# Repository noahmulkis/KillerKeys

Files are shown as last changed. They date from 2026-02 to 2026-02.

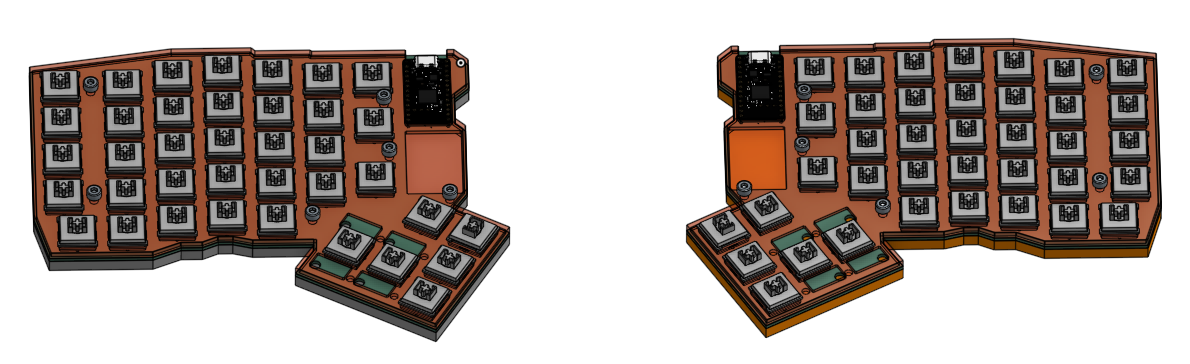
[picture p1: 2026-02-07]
Github/README/Screenshot 2026-02-07 160610.png

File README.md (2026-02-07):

# KillerKeys

This is KillerKeys, A super low profile, 3dprintable, pcb based custom keyboard, using a nice!nano knockoff mc.  

## Required Parts  
(Check BOM for exact details)

- microcontroller  
- 2x pcb (pcb is reversible)  
- 1 of each required 3d printed part  
- 6x m3x8 cap head machine screws  
- switch of choice (footprints can accomadate multiple brands, I am using reddragon low profile switches)  
- 3D printed keycaps (up to personal choice of colour / design)  
- Diodes (throughhole or smd)  

## Assembly instructions

1. Solder diodes to board top.  
2. Solder headers and microcontroller to top of board.  
3. For RHS board solder together pads to reverse direction, on LHS board solder "normal" side pads together.  
4. The microcontroller headers are needed to allow the USB-C port to be accessable.  
5. Push switches through top plates.  
6. Place top plate in place, filp board upside down, and solder the switches in place.  
7. Solder Battery onto board, and place in hole in PCB.  
8. Screw bottom case in place.  
9. Flash KMK firmware.  

## Images





Schematic

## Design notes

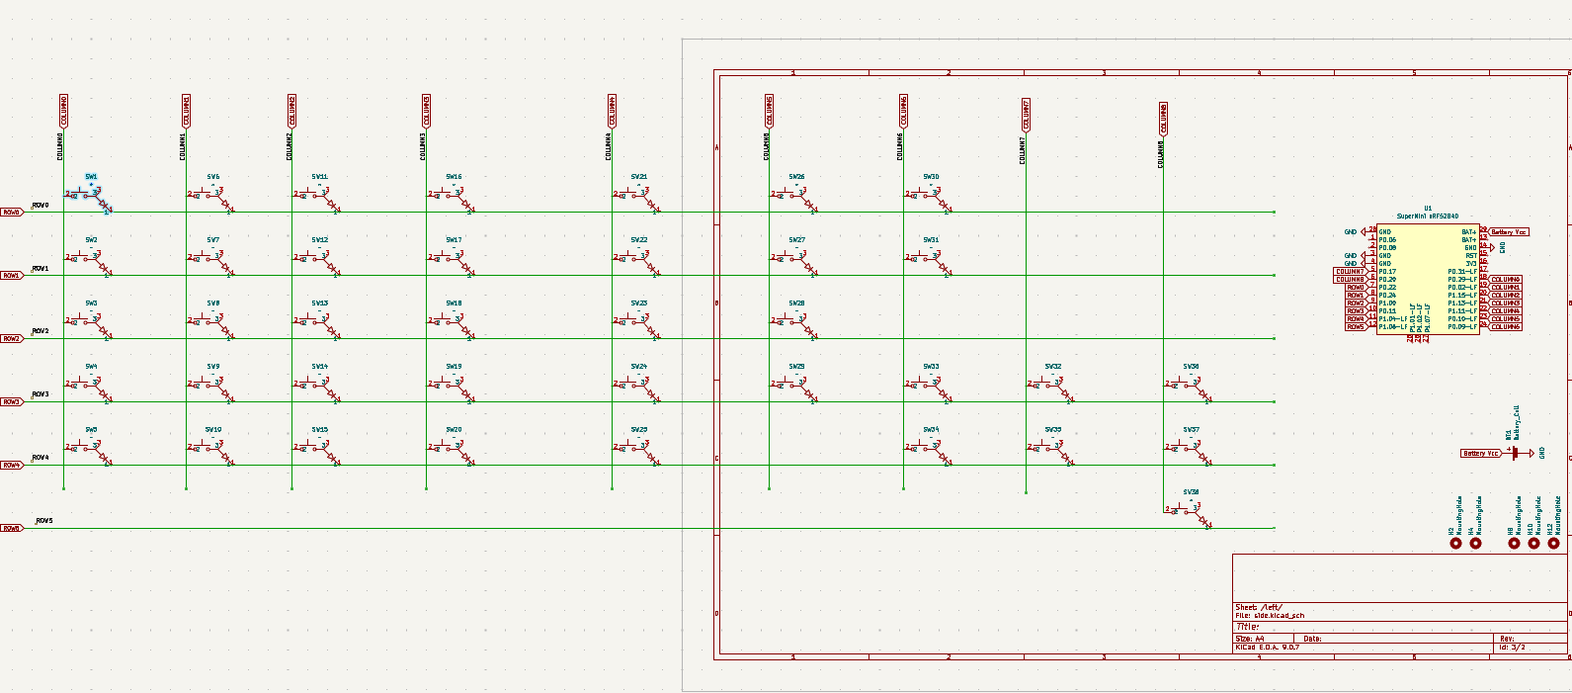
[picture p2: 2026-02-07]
Github/README/Schematic.png

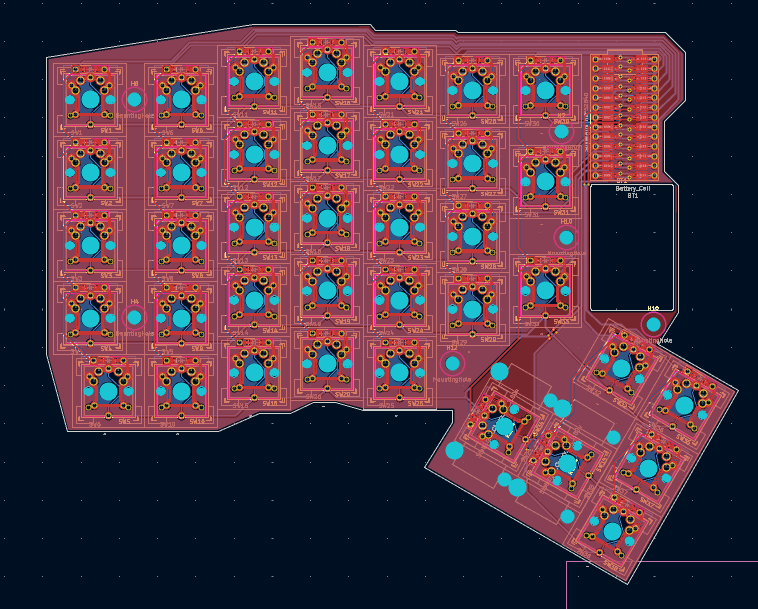
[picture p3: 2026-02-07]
Github/README/Screenshot 2026-02-07 161123.png

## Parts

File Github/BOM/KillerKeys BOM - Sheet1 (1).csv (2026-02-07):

CPN | Part Name | Description | Unit price | Quantity | Total price | Link
1 | Pro Micro nRF52840 | Microcontroller 2x | 2.83 | 2 | 5.66 | https://www.aliexpress.com/item/1005006271881076.html
2 | Switches | reddragon low profile |  |  | 10.73 | https://www.aliexpress.com/item/1005008633373890.html?curPageLogUid=tXnkem2xSMqb
3 | Diodes | 1N5819 THR DIODE 76x | 1.15 | 2 | 2.3 | https://www.aliexpress.com/item/1005001552094086.html?curPageLogUid=bXqkzmMptUZg
4 | Stabilizers | 4-2U 1- 6.25U |  |  | 10.89 | https://www.aliexpress.com/item/1005005296240590.html?curPageLogUid=bUBv3HwUEil0
5 | PCB's | JLCPCB order (both pcb's) inc. shipping | 22.4 | 1 | $14.30 | https://cart.jlcpcb.com/quote?stencilLayer=2&stencilWidth=100&stencilLength=100&stencilCounts=5&plateType=1
6 | Hardware/Screws | YMMV spprx £0 -- 6x m3x8 cap head
7 | Batteries | 1s Lipo 33x21x10mm or smaller |  | 1 | 2.06 | https://www.aliexpress.com/item/1005009176692643.html?curPageLogUid=KsSvs5md74Hk
Running Total | £45.94
Total dollars | £62.48 | plus shipping

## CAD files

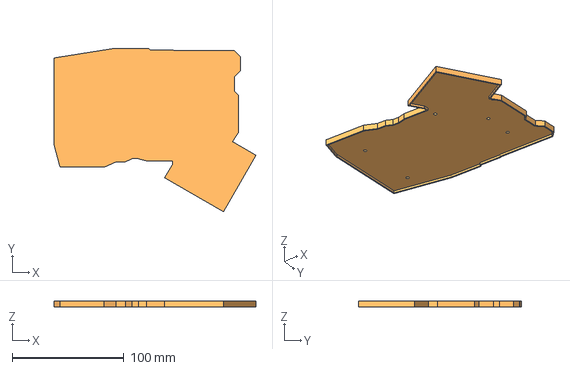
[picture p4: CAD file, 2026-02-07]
Github/CAD/3D printed parts only/RH-Bottom.step
181.0 x 146.5 x 5.00 mm

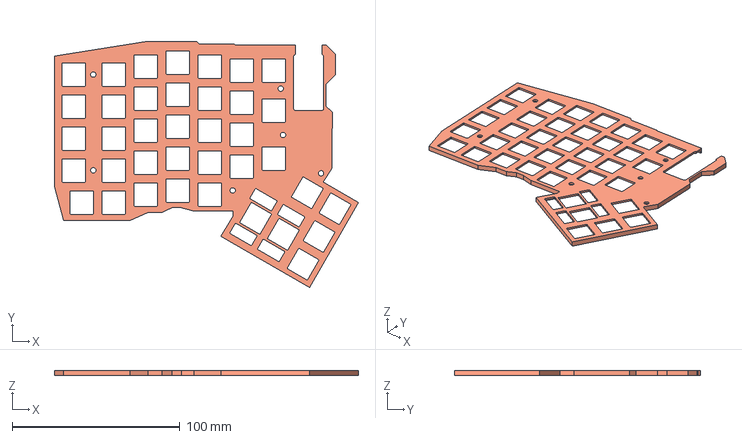
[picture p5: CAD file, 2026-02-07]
Github/CAD/3D printed parts only/LH-Top.step
181.0 x 146.5 x 3.10 mm

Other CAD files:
Github/CAD/3D printed parts only/LH-Bottom.step
Github/CAD/3D printed parts only/RH-Top.step

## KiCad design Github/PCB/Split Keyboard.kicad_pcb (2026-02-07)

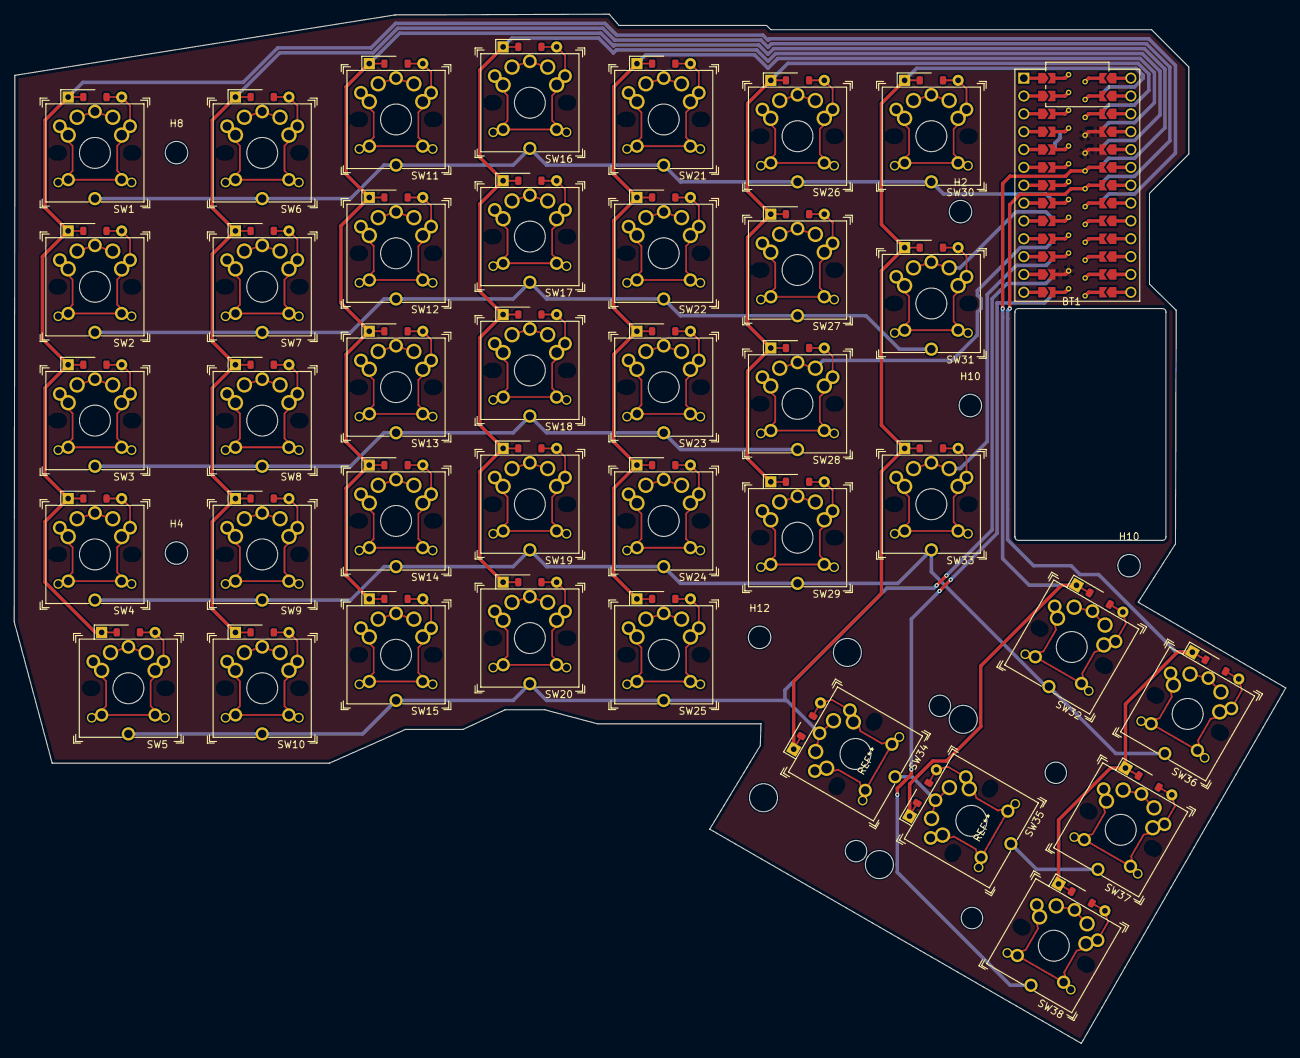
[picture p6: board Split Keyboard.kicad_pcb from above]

Board: 2 copper layers, 181.0 x 146.5 mm, 46 parts (0 on the bottom side), 16 nets.

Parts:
BT1: Battery_Cell; 503020 battery hole
H2, H4, H8, H10, H10#2, H12: MountingHole; MountingHole_3.2mm_M3
SW1, SW2, SW3, SW4, SW5, SW6, SW7, SW8, SW9, SW10, SW11, SW12, SW13, SW14, SW15, SW16, SW17, SW18, SW19, SW20, SW21, SW22, SW23, SW24, SW25, SW26, SW27, SW28, SW29, SW30, SW31, SW32, SW33, SW34, SW35, SW36, SW37, SW38: SW_UNIVERSAL_1.00u
U1: SuperMini nRF52840; ProMicro_DUAL_jumper

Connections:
COLUMN0: SW1.2, SW2.2, SW3.2, SW4.2, SW5.2, U1.18 (P0.29-LF)
COLUMN1: SW6.2, SW7.2, SW8.2, SW9.2, SW10.2, U1.19 (P0.02-LF)
COLUMN2: SW11.2, SW12.2, SW13.2, SW14.2, SW15.2, U1.20 (P1.15-LF)
COLUMN3: SW16.2, SW17.2, SW18.2, SW19.2, SW20.2, U1.21 (P1.13-LF)
COLUMN4: SW21.2, SW22.2, SW23.2, SW24.2, SW25.2, U1.22 (P1.11-LF)
COLUMN5: SW26.2, SW27.2, SW28.2, SW29.2, U1.23 (P0.10-LF)
COLUMN6: SW30.2, SW31.2, SW33.2, SW34.2, U1.24 (P0.09-LF)
COLUMN7: SW32.2, SW35.2, U1.5 (P0.17)
COLUMN8: SW36.2, SW37.2, SW38.2, U1.6 (P0.20)
GND: U1.3 (GND), U1.4 (GND), U1.14 (GND)
ROW0: SW1.1, SW6.1, SW11.1, SW16.1, SW21.1, SW26.1, SW30.1, U1.7 (P0.22)
ROW1: SW2.1, SW7.1, SW12.1, SW17.1, SW22.1, SW27.1, SW31.1, U1.8 (P0.24)
ROW2: SW3.1, SW8.1, SW13.1, SW18.1, SW23.1, SW28.1, U1.9 (P1.00)
ROW3: SW4.1, SW9.1, SW14.1, SW19.1, SW24.1, SW29.1, SW32.1, SW33.1, SW36.1, U1.10 (P0.11)
ROW4: SW5.1, SW10.1, SW15.1, SW20.1, SW25.1, SW34.1, SW35.1, SW37.1, U1.11 (P1.04-LF)
ROW5: SW38.1, U1.12 (P1.06-LF)

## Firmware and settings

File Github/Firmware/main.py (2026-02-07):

import board
import digitalio
from kmk.extensions.media_keys import MediaKeys
from kmk.handlers.sequences import send_string, simple_key_sequence
from kmk.keyboard import KMKKeyboard
from kmk.keys import KC
from kmk.modules.layers import Layers
from kmk.modules.split_keyboards import Split, SplitSide
from kmk.scanners.keypad import KeysScanner
from kmk.scanners.matrix import MatrixScanner

# Initialize keyboard
keyboard = KMKKeyboard()

# Split keyboard configuration
split_side = SplitSide.LEFT  # Change to RIGHT for right half
split = Split(split_side=split_side)
keyboard.modules.append(split)

# Add layers support
keyboard.modules.append(Layers())

# Add media keys
keyboard.extensions.append(MediaKeys())

# Matrix configuration 
# ROWS and COLS 
keyboard.matrix = MatrixScanner(
    row_pins=(board.P0_04, board.P0_05, board.P0_06, board.P0_07, board.P0_08),
    col_pins=(board.P0_09, board.P0_10, board.P0_11, board.P0_12, board.P0_13, board.P0_14, board.P0_15),
)

# UART pins for split communication 
keyboard.uart_pin_tx = board.P1_06
keyboard.uart_pin_rx = board.P1_05

# Keymap 
keyboard.keymap = [
    [
        # Layer 0
        KC.ESC, KC.N1, KC.N2, KC.N3, KC.N4, KC.N5, KC.NO,
        KC.TAB, KC.Q, KC.W, KC.E, KC.R, KC.T, KC.NO,
        KC.CAPS, KC.A, KC.S, KC.D, KC.F, KC.G,
        KC.LSFT, KC.Z, KC.X, KC.C, KC.V, KC.B, KC.NO,
        KC.LCTL, KC.LALT, KC.LGUI, KC.MO(1), KC.SPC,
        
        # Right half
        KC.NO, KC.N6, KC.N7, KC.N8, KC.N9, KC.N0, KC.MINS,
        KC.NO, KC.Y, KC.U, KC.I, KC.O, KC.P, KC.BSLS,
        KC.H, KC.J, KC.K, KC.L, KC.SCLN, KC.QUOT,
        KC.NO, KC.N, KC.M, KC.COMM, KC.DOT, KC.SLSH, KC.RSFT,
        KC.ENT, KC.MO(1), KC.RGUI, KC.RALT, KC.RCTL,
    ]
]

if __name__ == '__main__':
    keyboard.go()
